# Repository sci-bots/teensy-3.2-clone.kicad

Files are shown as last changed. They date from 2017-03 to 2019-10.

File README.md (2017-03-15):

# Teensy 3.2 reference board clone

Teensy 3.2 reference board recreated in KiCad. This is based on a conversion of the original [eagle project](https://github.com/thewknd/teensy-boards) by [thewknd](https://github.com/thewknd).

teensy3 ref board clone

Shared basket at mouser: http://www.mouser.com/ProjectManager/ProjectDetail.aspx?AccessID=719df5721e

Pre-programmed Bootloader Chip for DIY Teensy LC & 3.2 Projects: http://pjrc.com/store/ic_mkl02.html (IC_MKL04Z32_TQFP32)

Shared project on osh park: https://www.oshpark.com/shared_projects/h2HB6bQQ

### What is different from the "original" Teensy 3.2 DIY Reference Board

PJRC Teensy 3.2 DIY Reference Board https://www.oshpark.com/shared_projects/d3J03Zeb

- the silkscreen is a bit messed up  
  teensy3 ref board clone
- the actuator from the tactile switch is shorter (ALPS SKHHPKA010)

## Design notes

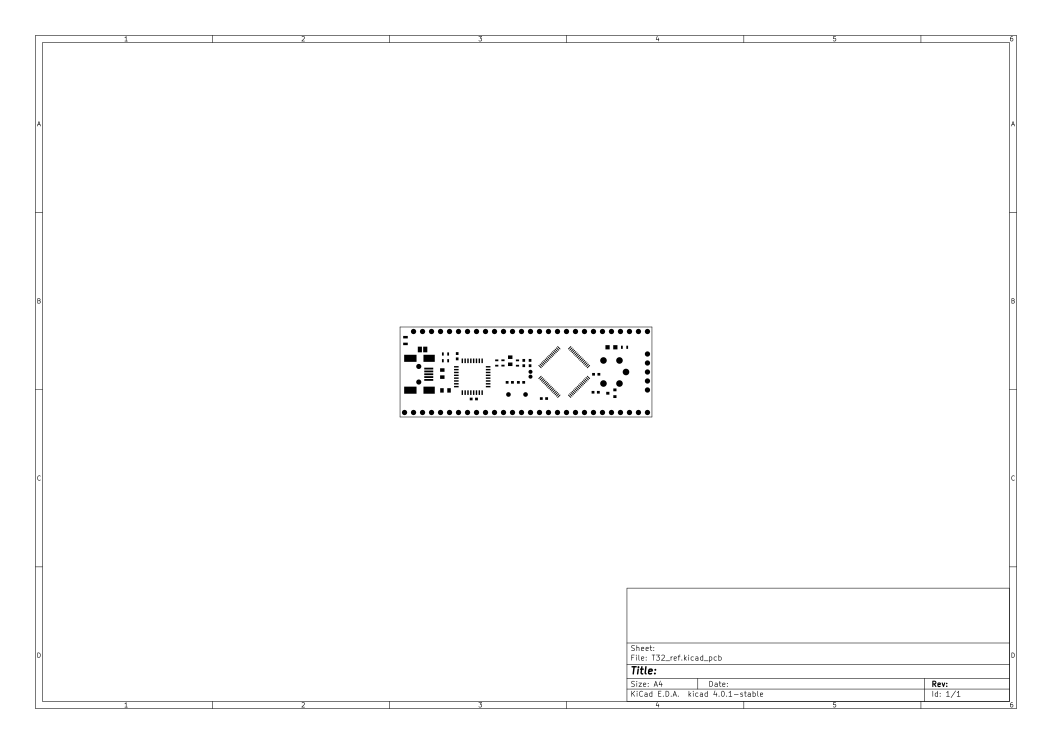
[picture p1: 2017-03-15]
png/T32_ref-F.Paste.png

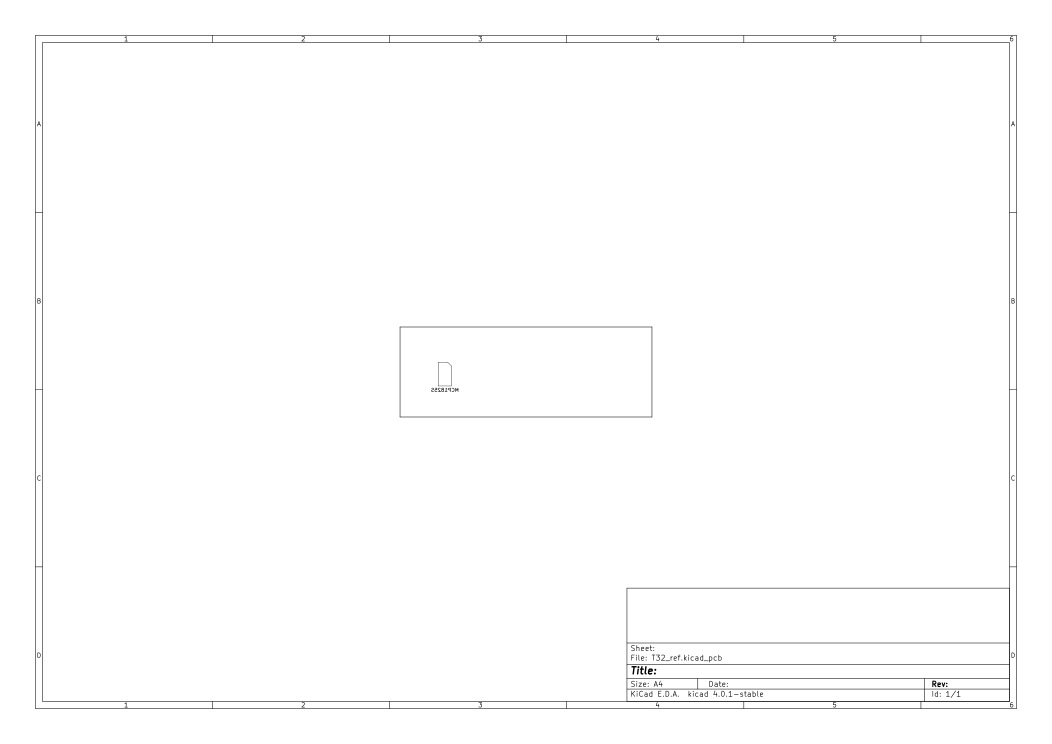
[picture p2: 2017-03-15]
png/T32_ref-B.Fab.png

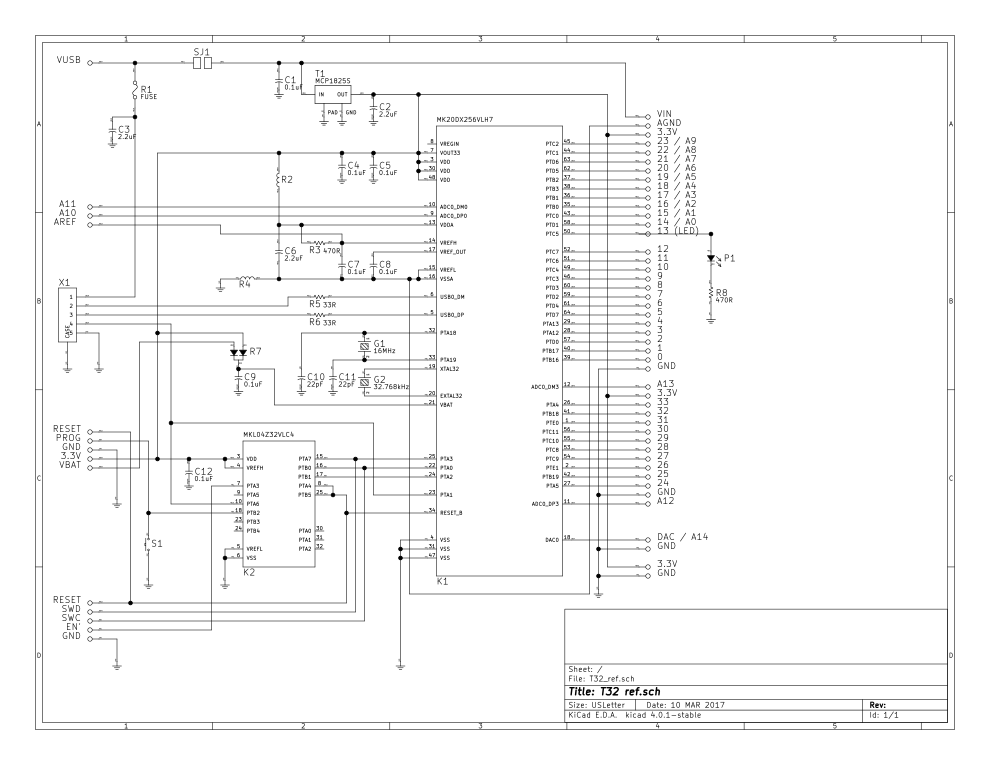
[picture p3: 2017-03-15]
png/T32_ref.png

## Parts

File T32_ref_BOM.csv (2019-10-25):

Reference | Value | Footprint | Count | Datasheet | Mfg_Part_No
C1, C4, C5, C7, C8, C9, C12 | 0.1uF | Capacitors_SMD:C_0603 | 7 |  | GRM188R71C104KA01D
C2, C3, C6 | 2.2uF | Capacitors_SMD:C_0805 | 3 |  | TMK212B7225KG-TR
C10, C11 | 22pF | Capacitors_SMD:C_0603 | 2 |  | VJ0603A220JXACW1BC
G1 | 16MHz | T32 ref:HC49US | 1 |  | ABL-16.000MHz-B1U
G2 | 32.768kHz | T32 ref:TC26H | 1 |  | CFS206-32.768KDZF-UB
K1 | MK20DX256VLH7 | T32 ref:LQFP64-05 | 1 |  | MK20DX256VLH7
K2 | MKL04Z32VLC4 | T32 ref:LQFP32-08 | 1
P1 | ~ | LEDs:LED_0805 | 1 |  | SML-211DTT86
R1 | FUSE | Resistors_SMD:R_0805 | 1 |  | 0ZCK0050FF2E
R2, R4 | ~ | Resistors_SMD:R_0603 | 2 |  | BLM18AG601SN1D
R3, R8 | 470R | Resistors_SMD:R_0603 | 2 |  | CRCW0603470RFKEA
R5, R6 | 33R | Resistors_SMD:R_0603 | 2 |  | ERJ-PA3F33R0V
R7 | ~ | TO_SOT_Packages_SMD:SOT-23 | 1 |  | BAT54C,215
S1 | ~ | T32 ref:ALPS_SKHH | 1 |  | SKHHPKA010
SJ1 | ~ | T32 ref:SOLDERJUMPER | 1
T1 | MCP1825S | TO_SOT_Packages_SMD:SOT-223 | 1 |  | MCP1825S-3302E/DB
X1 | MINI-USB | T32 ref:MOLEX_SD-67503-010 | 1 |  | 67503-1020

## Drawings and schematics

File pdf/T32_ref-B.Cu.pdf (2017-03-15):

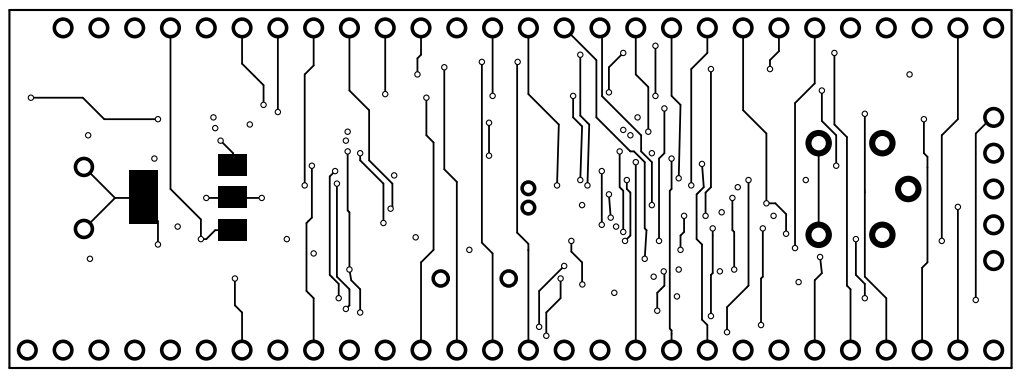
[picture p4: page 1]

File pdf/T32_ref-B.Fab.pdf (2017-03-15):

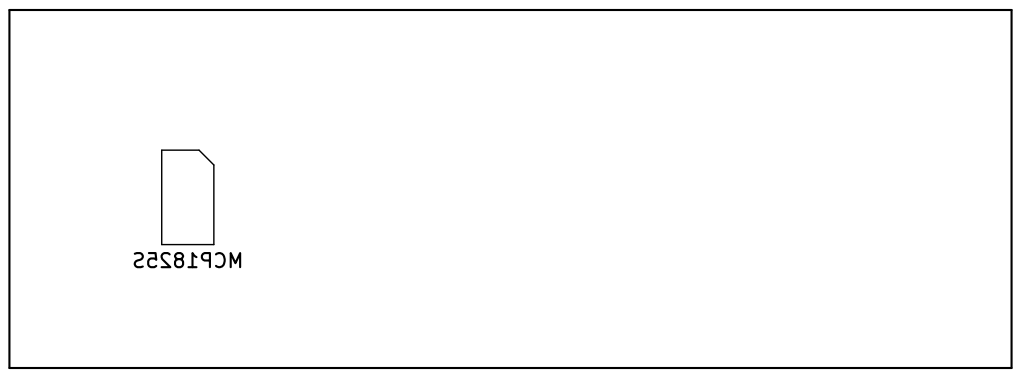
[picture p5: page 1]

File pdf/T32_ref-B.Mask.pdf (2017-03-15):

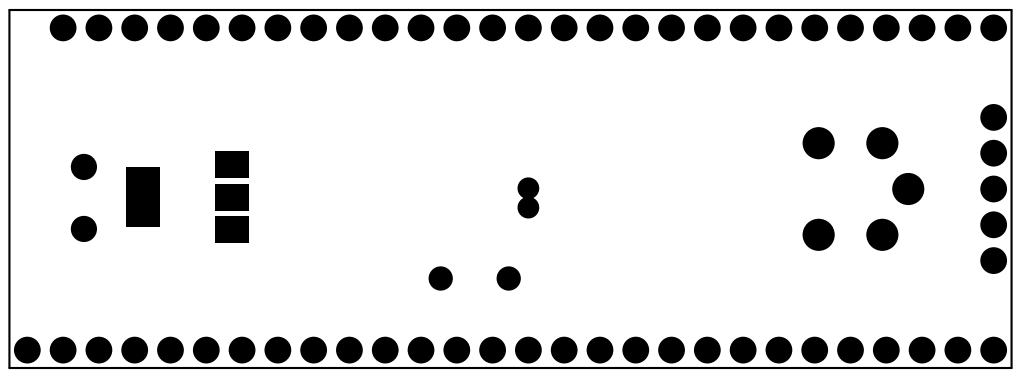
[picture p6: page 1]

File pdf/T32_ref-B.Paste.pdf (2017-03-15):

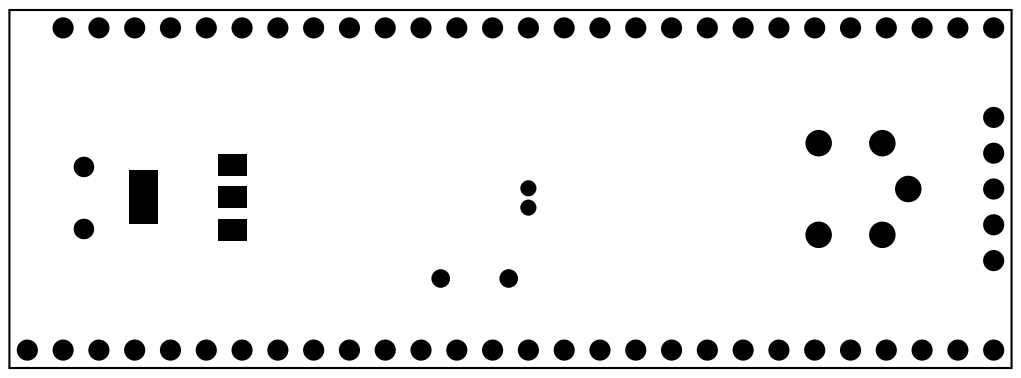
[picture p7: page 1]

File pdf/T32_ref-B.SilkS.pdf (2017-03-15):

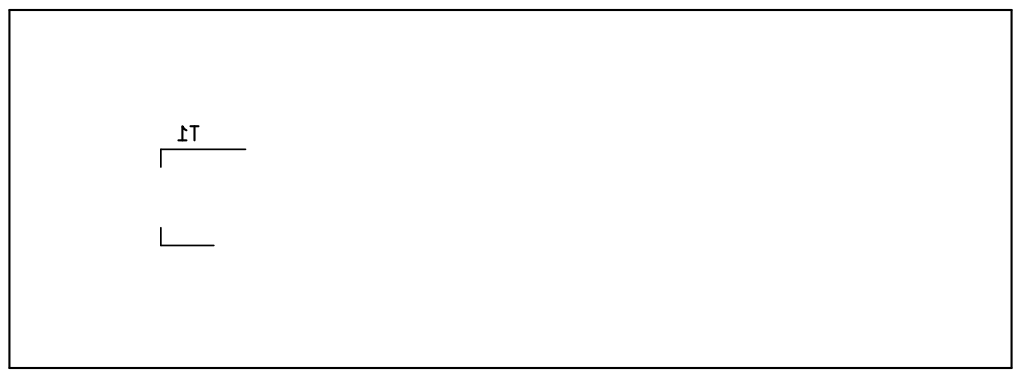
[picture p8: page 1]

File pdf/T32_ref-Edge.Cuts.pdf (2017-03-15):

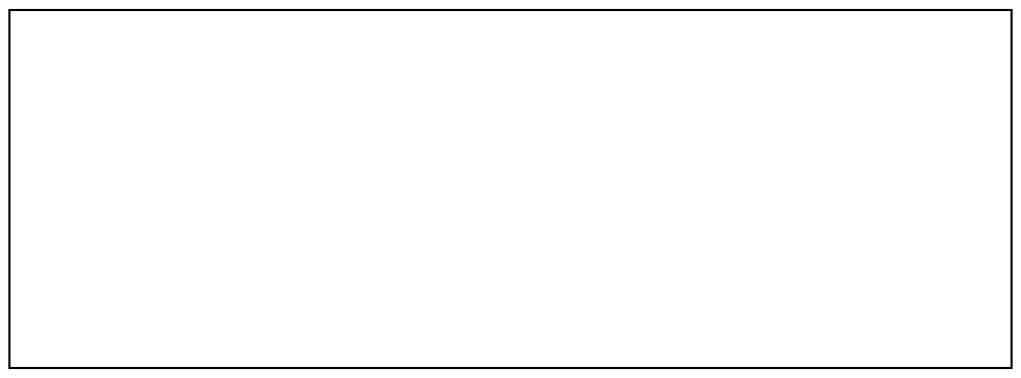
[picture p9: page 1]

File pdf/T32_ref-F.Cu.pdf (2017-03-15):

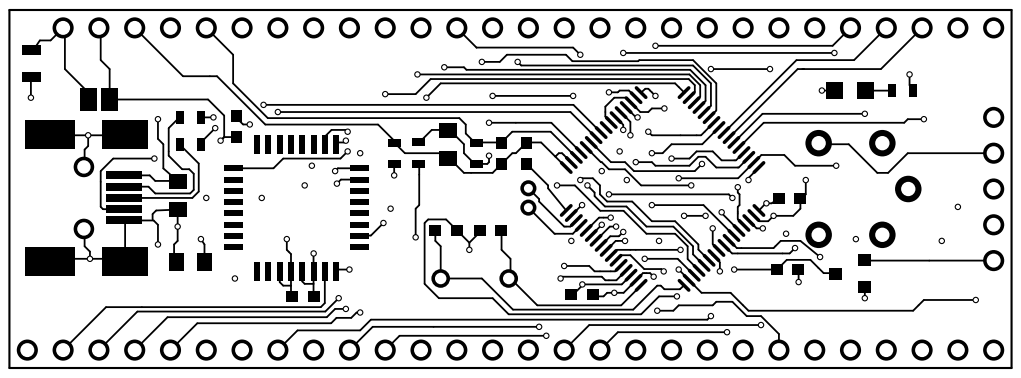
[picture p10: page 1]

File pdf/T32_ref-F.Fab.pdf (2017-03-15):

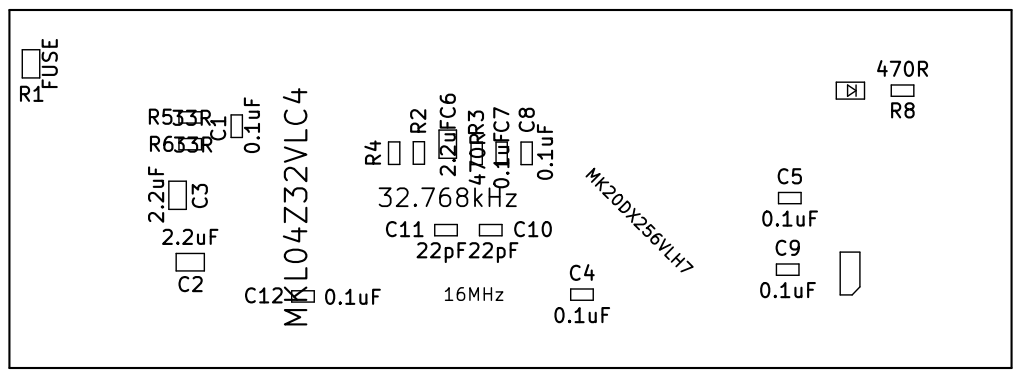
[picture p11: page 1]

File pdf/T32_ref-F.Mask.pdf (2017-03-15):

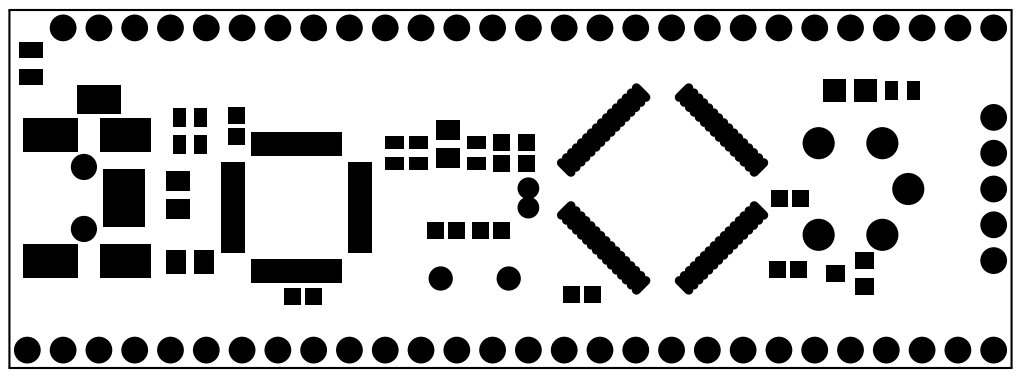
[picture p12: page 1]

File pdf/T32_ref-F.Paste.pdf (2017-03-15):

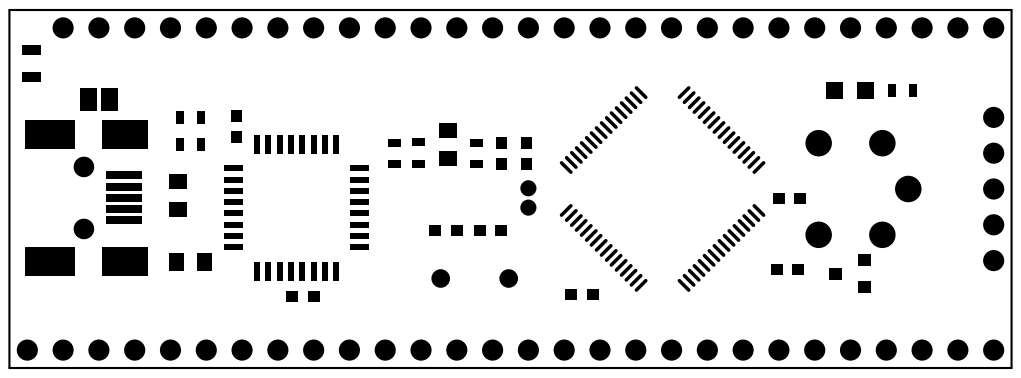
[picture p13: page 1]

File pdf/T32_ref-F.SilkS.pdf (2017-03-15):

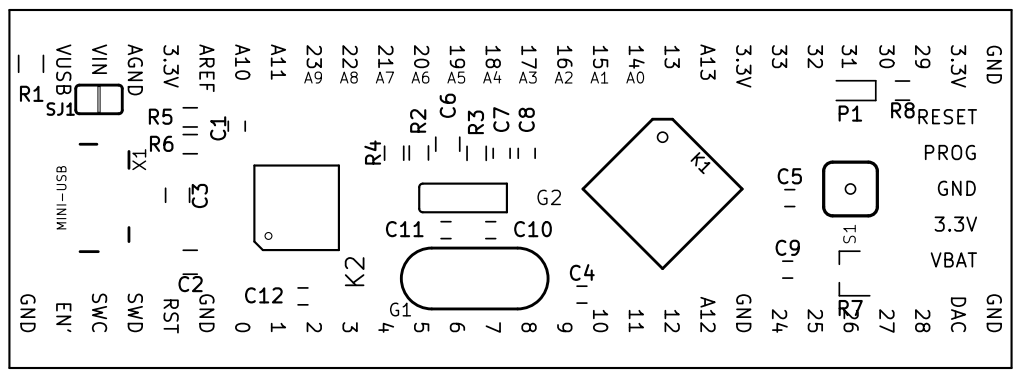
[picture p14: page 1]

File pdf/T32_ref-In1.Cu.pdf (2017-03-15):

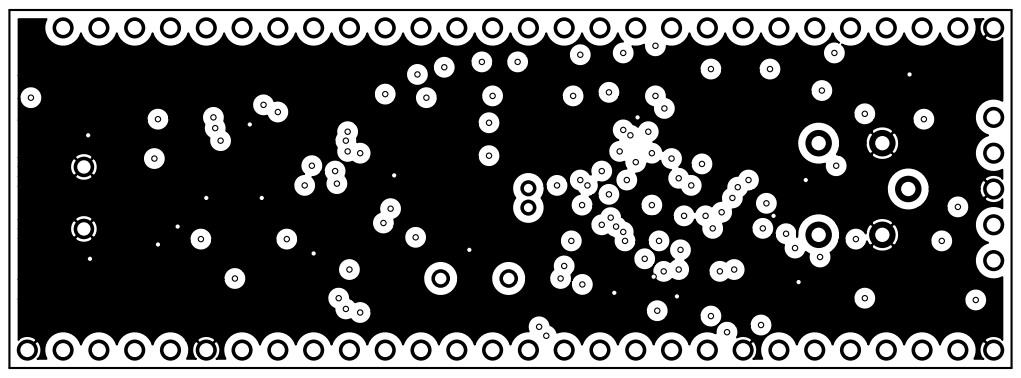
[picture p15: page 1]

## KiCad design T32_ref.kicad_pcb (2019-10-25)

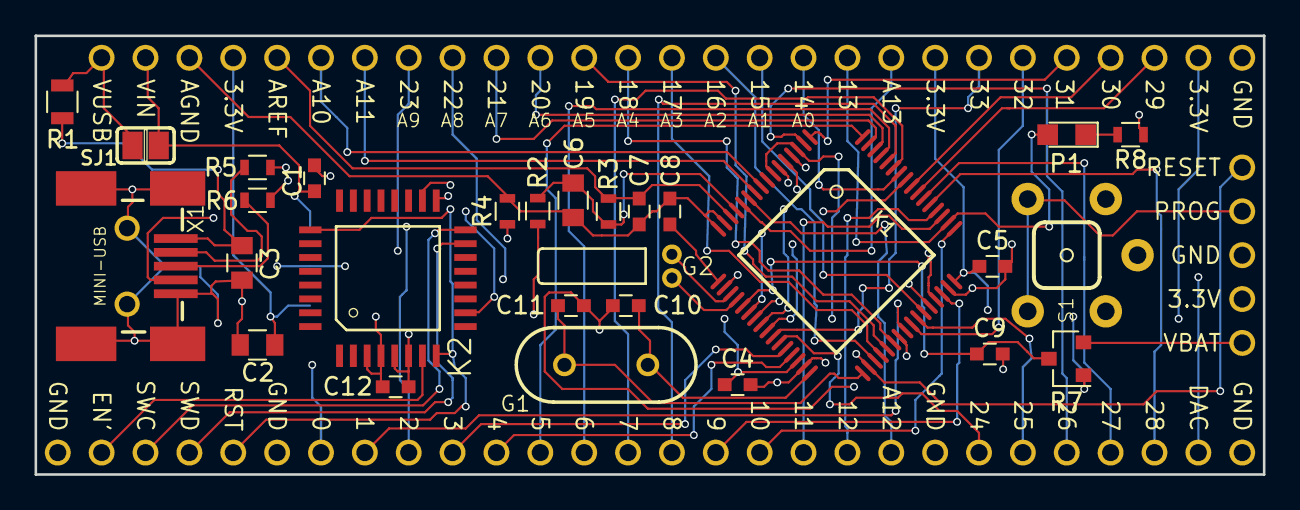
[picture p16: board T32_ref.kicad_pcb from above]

Board: 4 copper layers, 71.1 x 25.4 mm, 89 parts (1 on the bottom side), 66 nets.

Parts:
C1, C4, C5, C7, C8, C9, C12: 0.1uF; C_0603
C2, C3, C6: 2.2uF; C_0805
C10, C11: 22pF; C_0603
G1: 16MHz; HC49US
G2: 32.768kHz; TC26H
K1: MK20DX256VLH7; LQFP64-05
K2: MKL04Z32VLC4; LQFP32-08
P1: LED_0805
R1: FUSE; R_0805
R2, R4: R_0603
R3, R8: 470R; R_0603
R5, R6: 33R; R_0603
R7: SOT-23
S1: ALPS_SKHH
SJ1: SOLDERJUMPER
SX1, SX2, SX3, SX4, SX5, SX6, SX7, SX8, SX9, SX10, SX11, SX12, SX13, SX14, SX15, SX16, SX17, SX18, SX19, SX20, SX21, SX22, SX23, SX24, SX25, SX26, SX27, SX28, SX29, SX30, SX31, SX32, SX33, SX34, SX35, SX36, SX37, SX38, SX39, SX40, SX41, SX42, SX43, SX44, SX45, SX46, SX47, SX48, SX49, SX50, SX51, SX52, SX53, SX54, SX55, SX56, SX57, SX58, SX59, SX60: PIN; PTH_39MIL
T1: MCP1825S; SOT-223
X1: MINI-USB; MOLEX_SD-67503-010

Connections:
/N$1: K2.7, SX59.1
/N$2: K1.22, K2.16, SX58.1
/N$3: K1.24, K2.17
/N$5: C10.1, G1.1, K1.32
/N$6: C11.1, G1.2, K1.33
/N$7: G2.2, K1.19
/N$8: G2.1, K1.20
/N$9: K2.18, S1.1, S1.2, SX40.1
/N$10: K1.5, R6.2
/N$11: C8.1, K1.17
/N$12: K1.34, K2.8, K2.25, SX38.1, SX56.1
/N$13: C7.1, K1.14, R3.2, SX16.1
/N$14: K1.6, R5.2
/N$15: C6.1, K1.13, R2.1, R3.1
/N$16: R6.1, X1.3
/N$17: R5.1, X1.2
/N$18: C3.1, R1.1, X1.1
/N$19: K1.23, K2.10, X1.4
/N$21: K1.45, SX5.1
/N$22: K1.44, SX6.1
/N$23: K1.63, SX7.1
/N$24: K1.62, SX8.1
/N$25: K1.37, SX9.1
/N$26: K1.38, SX10.1
/N$27: K1.36, SX11.1
/N$28: K1.35, SX13.1
/N$29: K1.43, SX15.1
/N$30: K1.58, SX17.1
/N$31: K1.50, P1.2, SX18.1
/N$32: K1.52, SX19.1
/N$33: K1.51, SX20.1
/N$34: K1.49, SX21.1
/N$35: K1.46, SX22.1
/N$36: K1.60, SX23.1
/N$37: K1.59, SX24.1
/N$38: K1.61, SX25.1
/N$39: K1.64, SX26.1
/N$40: K1.29, SX27.1
/N$41: K1.28, SX28.1
/N$42: K1.57, SX29.1
/N$43: K1.40, SX30.1
/N$44: K1.39, SX31.1
/N$45: K1.12, SX33.1
/N$46: K1.26, SX35.1
/N$47: K1.41, SX36.1
/N$48: K1.1, SX37.1
/N$49: K1.56, SX39.1
/N$50: K1.55, SX41.1
/N$51: K1.53, SX43.1
/N$52: P1.1, R8.2
/N$53: C6.2, C7.2, C8.2, K1.15, K1.16, R4.2, SX3.1
/N$54: K1.18, SX52.1
/N$55: K1.11, SX51.1
/N$57: K1.27, SX49.1
/N$58: K1.42, SX48.1
/N$59: K1.2, SX47.1
/N$60: K1.54, SX45.1
/N$61: C1.1, SJ1.2, SX2.1, T1.1
/N$63: R7.2, SX46.1
/N$64: K1.10, SX12.1
/N$65: K1.9, SX14.1
/N$67: R1.2, SJ1.1, SX1.1
/N$68: C9.1, K1.21, R7.3
/N$69: C2.1, C4.1, C5.1, C12.1, K1.3, K1.7, K1.30, K1.48, K2.3, K2.4, R2.2, R7.1, SX4.1, SX34.1, SX44.1, SX54.1, T1.3
/N$70: K1.25, K2.15, SX57.1
GND: C1.2, C2.2, C3.2, C4.2, C5.2, C9.2, C10.2, C11.2, C12.2, K1.4, K1.31, K1.47, K2.5, K2.6, R4.1, R8.1, S1.3, S1.4, SX32.1, SX42.1, SX50.1, SX53.1, SX55.1, SX60.1, T1.2, T1.4, X1.5, X1.P$1, X1.P$2, X1.P$3, X1.P$4, X1.P$5, X1.P$6

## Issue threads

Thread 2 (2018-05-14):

Wrong part # for 0.1uF capacitor in bill of materials

thewknd, 2018-05-14:
GRM155R71A104KA01D comes with a 0402 footprint. On the pcb is a 0603 footprint.

ryanfobel, 2019-10-24:
> GRM155R71A104KA01D comes with a 0402 footprint. On the pcb is a 0603 footprint.

Thanks for the update.

Closed 2019-10-24.

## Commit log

2017-03-10 KiCad conversion of thewknd's reference design
    https://github.com/thewknd/teensy-boards/tree/master/Teensy%203.2%20reference%20board%20clone
    [T32 ref.brd, T32 ref.kicad_pcb, T32 ref.sch]
2017-03-15 Convert to new library format and fix DRC errors
    [T32 ref.brd, T32 ref.kicad_pcb, T32 ref.sch]
2017-03-15 Replace common footprints with KiCad versions
    [T32 ref.kicad_pcb, T32 ref.sch]
2017-03-15 Add part numbers to schematic and export BOM
    [T32 ref.sch, T32 ref_BOM.csv]
2017-03-15 Remove space from paths
    [T32 ref.sch, T32_ref.kicad_pcb, T32_ref.sch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]
2017-03-15 Add gerber, svg, png and pdf outputs
    [T32_ref-B.Mask.gbr, T32_ref-B.SilkS.gbr, T32_ref-Bottom.gbr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]
2017-03-30 Add 1-click-bom.tsv for kitnic.it test
    [1-click-bom.tsv]
2018-03-26 Make compatible with kitspace.org
    [1-click-bom.tsv]
2019-10-24 Fix cap footprint
    Fixes #2
    [T32_ref.sch, T32_ref_BOM.csv]
2019-10-24 Rename front and bottom copper gerber layers
    What's that gerber couldn't deal with the names you chose yet. Switching
    to the KiCad defaults.
    https://github.com/tracespace/tracespace/tree/master/packages/whats-that-gerber
    [T32_ref-B.Cu.gbr, T32_ref-F.Cu.gbr]
2019-10-24 Remove SX* pin holes from BOM
    [T32_ref_BOM.csv]
2019-10-25 Update kicad_pcb and pro to use new layer names
    [T32_ref-B.SilkS.gbr, T32_ref-B_Cu.gbr, T32_ref-B_Mask.gbr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]
